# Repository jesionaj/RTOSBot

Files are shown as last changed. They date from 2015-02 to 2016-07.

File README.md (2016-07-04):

# RTOSBot
A small robot that uses my [HobbyOS](https://github.com/jesionaj/HobbyOS/) code. A video describing this project can be found [here](https://www.youtube.com/watch?v=qPOtINk6i20).

Robot

Parallax's Board of Education shield is the base of the robot, which includes the frame, motors, and encoders. For the brains, I laid out my own PCB with a PIC32MX250F128B chip, which you can find in the hardware folder.

PCB

The robot is driven using Wiimote Nunchuck. While it drives, the LCD on top displays encoder data and joystick position, which is also written to an SD card. After the driving is finished, that data can be copied off of the SD card (see below). An included Python script reads this data and reconstructs the robot's path using dead reckoning.

### Build Instructions
1. Run `git clone https://github.com/jesionaj/HobbyOS.git` in the RTOSBot folder.  
2. Open the RTOSBot project in MPLAB and hit build. That's it!

### Dead Reckoning  
The dead reckoning script requires Python 2.7, pygame 1.9.2, and numpy. Data is recorded on the SD card starting at address 0x400.  
1. Open the `python` folder and copy the data off the robot's SD card using (for OSX at least): `sudo dd bs=512 skip=2 if=/dev/rdisk# of=sdcard_data count=20`, where # is the SD card's disk number. Sample data is provided.  
2. Run `python InterpretFile.py sdcard_data`  
3. Before removing the SD card, run `sudo dd bs=512 seek=2 if=/dev/zero of=/dev/rdisk# count=20` to wipe out the old run.

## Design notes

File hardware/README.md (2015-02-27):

Included here are the Eagle project files for the PCB, as well as the gerber output.

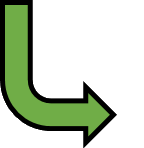
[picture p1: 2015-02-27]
python/img/orig/BackwardRight.png

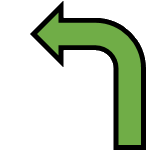
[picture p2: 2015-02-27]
python/img/orig/ForwardLeft.png

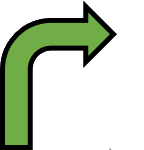
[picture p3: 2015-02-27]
python/img/orig/ForwardRight.png

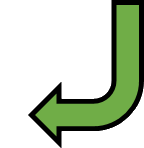
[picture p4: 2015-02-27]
python/img/orig/BackwardLeft.png

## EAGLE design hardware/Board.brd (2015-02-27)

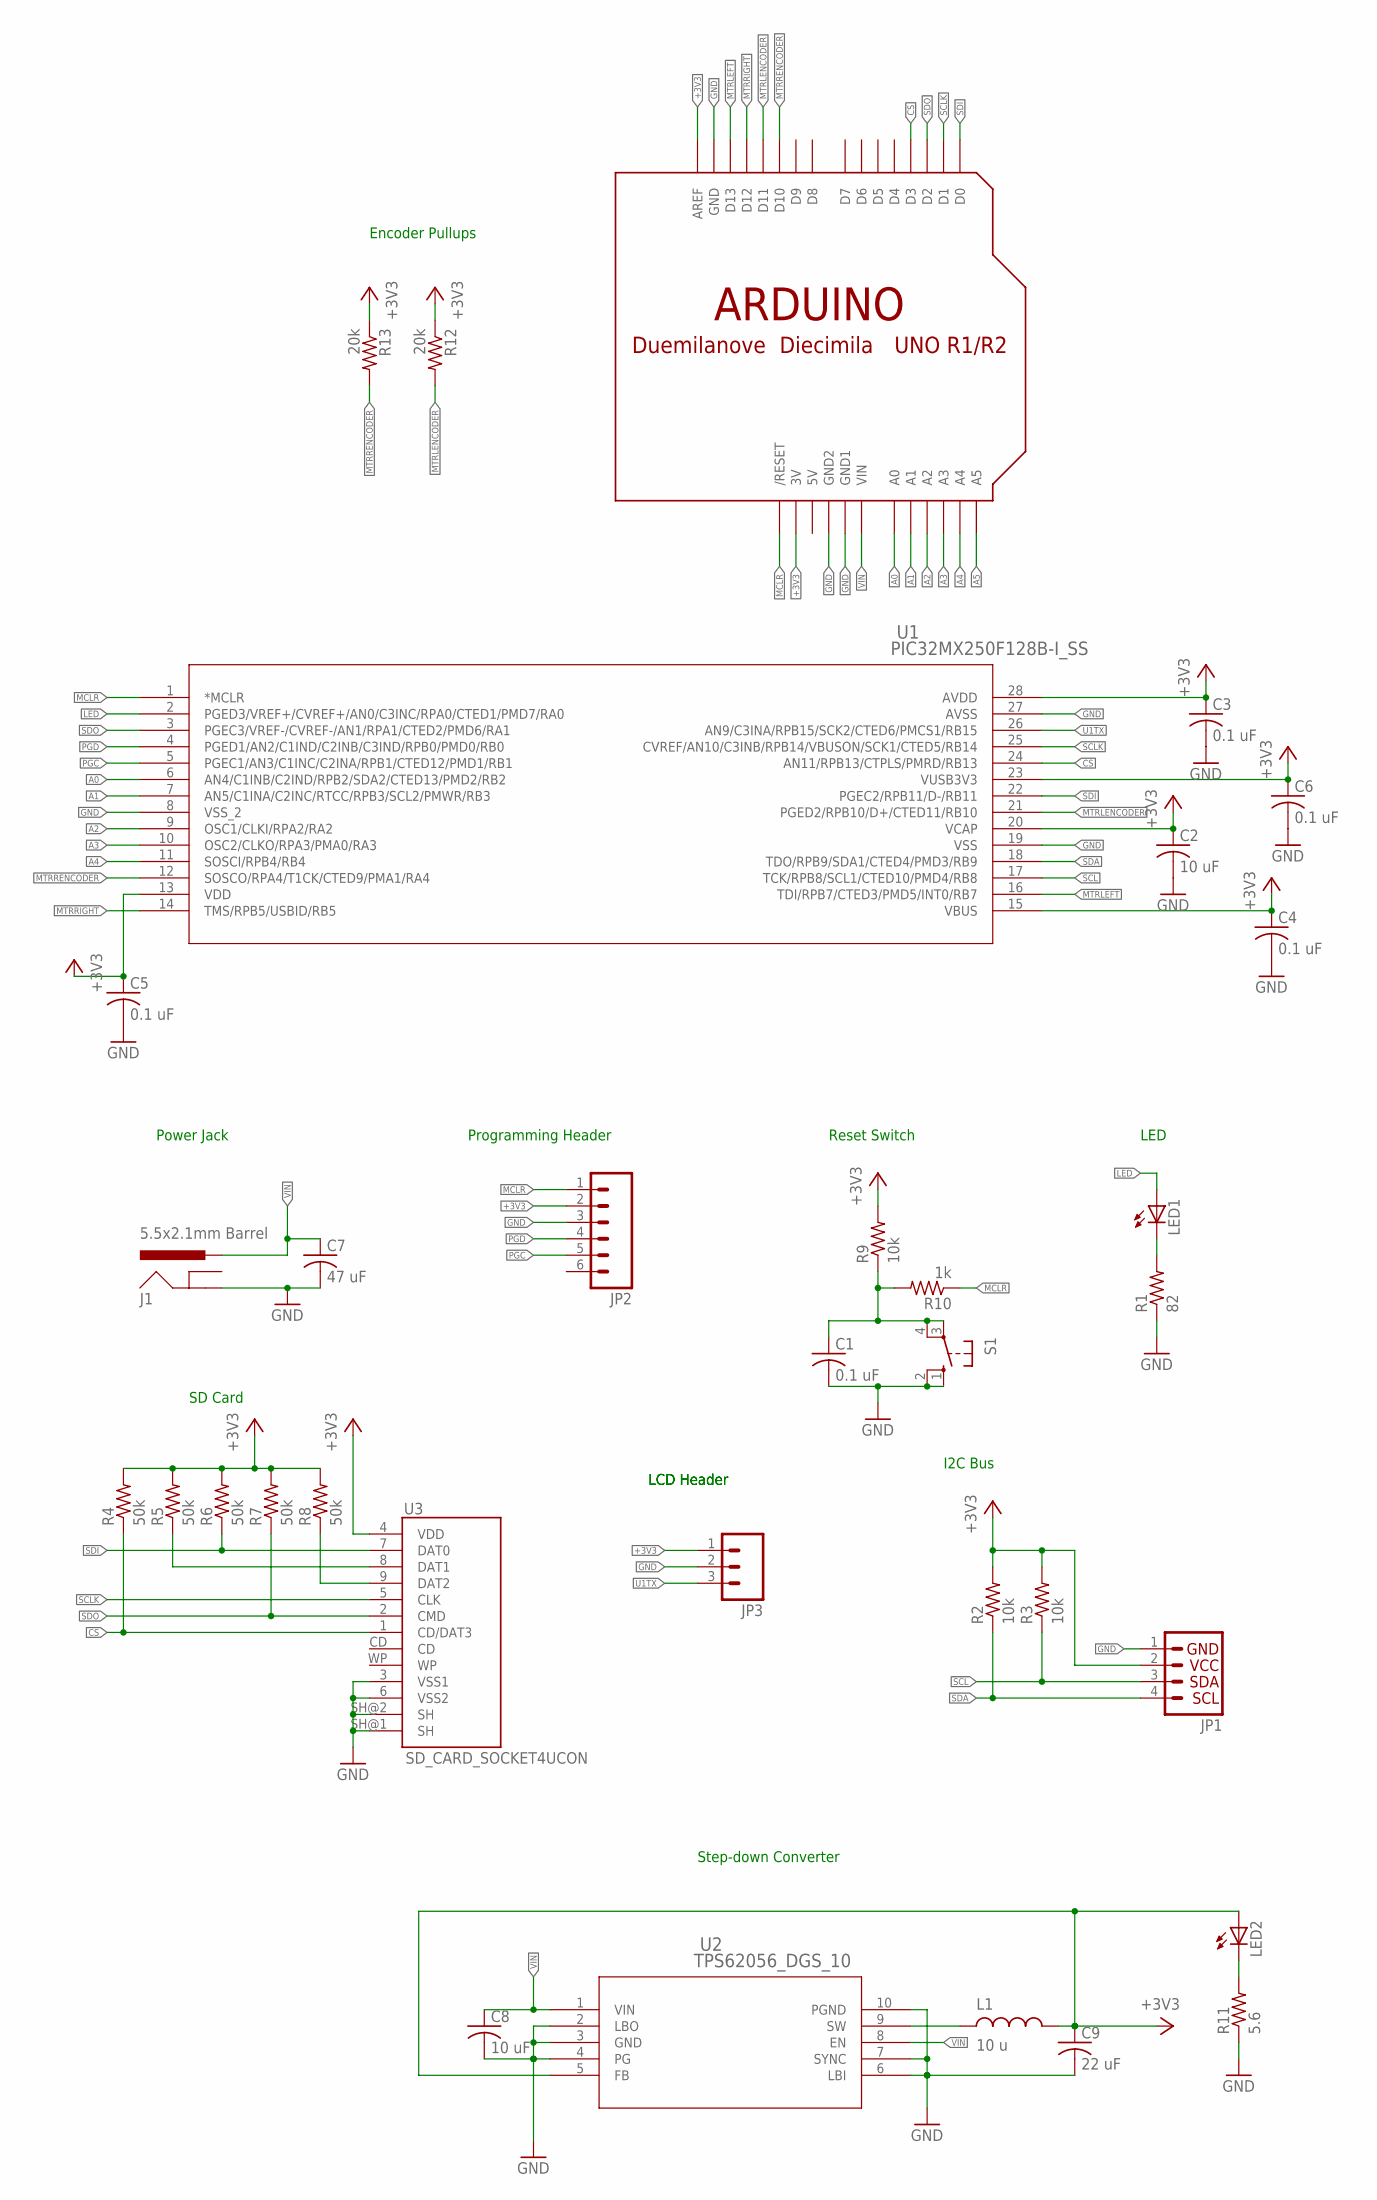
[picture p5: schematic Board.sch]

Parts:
C1, C3, C4, C5, C6: 0.1 uF; C0805
C2, C8: 10 uF; C0805
C7: 47 uF; C0805
C9: 22 uF; C0805
J1: 5.5x2.1mm Barrel; POWER_JACK_SMD
JP1: I2C_STANDARD; 1X04
JP2: M06SILK_FEMALE_PTH; 1X06
JP3: M03PTH; 1X03
L1: 10 u; SLF7032T-100M1R4-2PF
LED1, LED2: LEDCHIPLED_1206; CHIPLED_1206
R1: 82; R1210W
R2, R3, R9: 10k; R0805W
R4, R5, R6, R7, R8: 50k; R0805W
R10: 1k; R0805W
R11: 5.6; R1210W
R12, R13: 20k; R0805W
S1: 10-XX; B3F-10XX
U1: PIC32MX250F128B-I_SS; SSOP28_MC
U2: TPS62056_DGS_10; DGS10
U3: SD_CARD_SOCKET4UCON; SDCARD_4UCONN
U$1: ARDUINO-NOHOLE

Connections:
5V: U$1.5V
+3V3: C2.1, C3.1, C4.1, C5.1, C6.1, C9.1, JP1.2, JP2.2, JP3.1, L1.P$2, LED2.A, R2.2, R3.2, R4.2, R5.2, R6.2, R7.2, R8.2, R9.2, R12.1, R13.1, U1.13 (VDD), U1.15 (VBUS), U1.20 (VCAP), U1.23 (VUSB3V3), U1.28 (AVDD), U2.5 (FB), U3.4 (VDD), U$1.3V, U$1.AREF
A0: U1.6 (AN4/C1INB/C2IND/RPB2/SDA2/CTED13/PMD2/R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), U$1.A0
A1: U1.7 (AN5/C1INA/C2INC/RTCC/RPB3/SCL2/PMWR/RB3), U$1.A1
A2: U1.9 (OSC1/CLKI/RPA2/RA2), U$1.A2
A3: U1.10 (OSC2/CLKO/RPA3/PMA0/RA3), U$1.A3
A4: U1.11 (SOSCI/RPB4/RB4), U$1.A4
A5: U$1.A5
CS: R4.1, U1.24 (AN11/RPB13/CTPLS/PMRD/RB13), U3.1 (CD/DAT3), U$1.D3
GND: C1.2, C2.2, C3.2, C4.2, C5.2, C6.2, C7.2, C8.2, C9.2, J1.P$4 (GND), JP1.1, JP2.3, JP3.2, R1.1, R11.1, S1.1 (S), S1.2 (S1), U1.8 (VSS_2), U1.19 (VSS), U1.27 (AVSS), U2.2 (LBO), U2.3 (GND), U2.4 (PG), U2.6 (LBI), U2.7 (SYNC), U2.10 (PGND), U3.3 (VSS1), U3.6 (VSS2), U3.SH@1 (SH), U3.SH@2 (SH), U$1.GND, U$1.GND1, U$1.GND2
LED: LED1.A, U1.2 (PGED3/VREF+/CVREF+/AN0/C3INC/RPA0/CTED1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)
MCLR: JP2.1, R10.1, U1.1 (*MCLR), U$1.RESET (/RESET)
MTRLEFT: U1.16 (TDI/RPB7/CTED3/PMD5/INT0/RB7), U$1.D13
MTRLENCODER: R12.2, U1.21 (PGED2/RPB10/D+/CTED11/RB10), U$1.D11
MTRRENCODER: R13.2, U1.12 (SOSCO/RPA4/T1CK/CTED9/PMA1/RA4), U$1.D10
MTRRIGHT: U1.14 (TMS/RPB5/USBID/RB5), U$1.D12
unnamed: LED1.C, R1.2
unnamed: R8.1, U3.9 (DAT2)
unnamed: R5.1, U3.8 (DAT1)
unnamed: C1.1, R9.1, R10.2, S1.3, S1.4 (P1)
unnamed: LED2.C, R11.2
unnamed: L1.P$1, U2.9 (SW)
PGC: JP2.5, U1.5 (PGEC1/AN3/C1INC/C2INA/RPB1/CTED12/PMD1/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)
PGD: JP2.4, U1.4 (PGED1/AN2/C1IND/C2INB/C3IND/RPB0/PMD0/R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)
SCL: JP1.3, R3.1, U1.17 (TCK/RPB8/SCL1/CTED10/PMD4/RB8)
SCLK: U1.25 (CVREF/AN10/C3INB/RPB14/VBUSON/SCK1/CTED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), U3.5 (CLK), U$1.D1
SDA: JP1.4, R2.1, U1.18 (TDO/RPB9/SDA1/CTED4/PMD3/RB9)
SDI: R6.1, U1.22 (PGEC2/RPB11/D-/RB11), U3.7 (DAT0), U$1.D0
SDO: R7.1, U1.3 (PGEC3/VREF-/CVREF-/AN1/RPA1/CTED2/PMD6/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), U3.2 (CMD), U$1.D2
U1TX: JP3.3, U1.26 (AN9/C3INA/RPB15/SCK2/CTED6/PMCS1/RB15)
VIN: C7.1, C8.1, J1.VIN0 (PWR), U2.1 (VIN), U2.8 (EN), U$1.VIN

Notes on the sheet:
Reset Switch
SD Card
Programming Header
Power Jack
LCD Header
LED
I2C Bus
Step-down Converter
Encoder Pullups

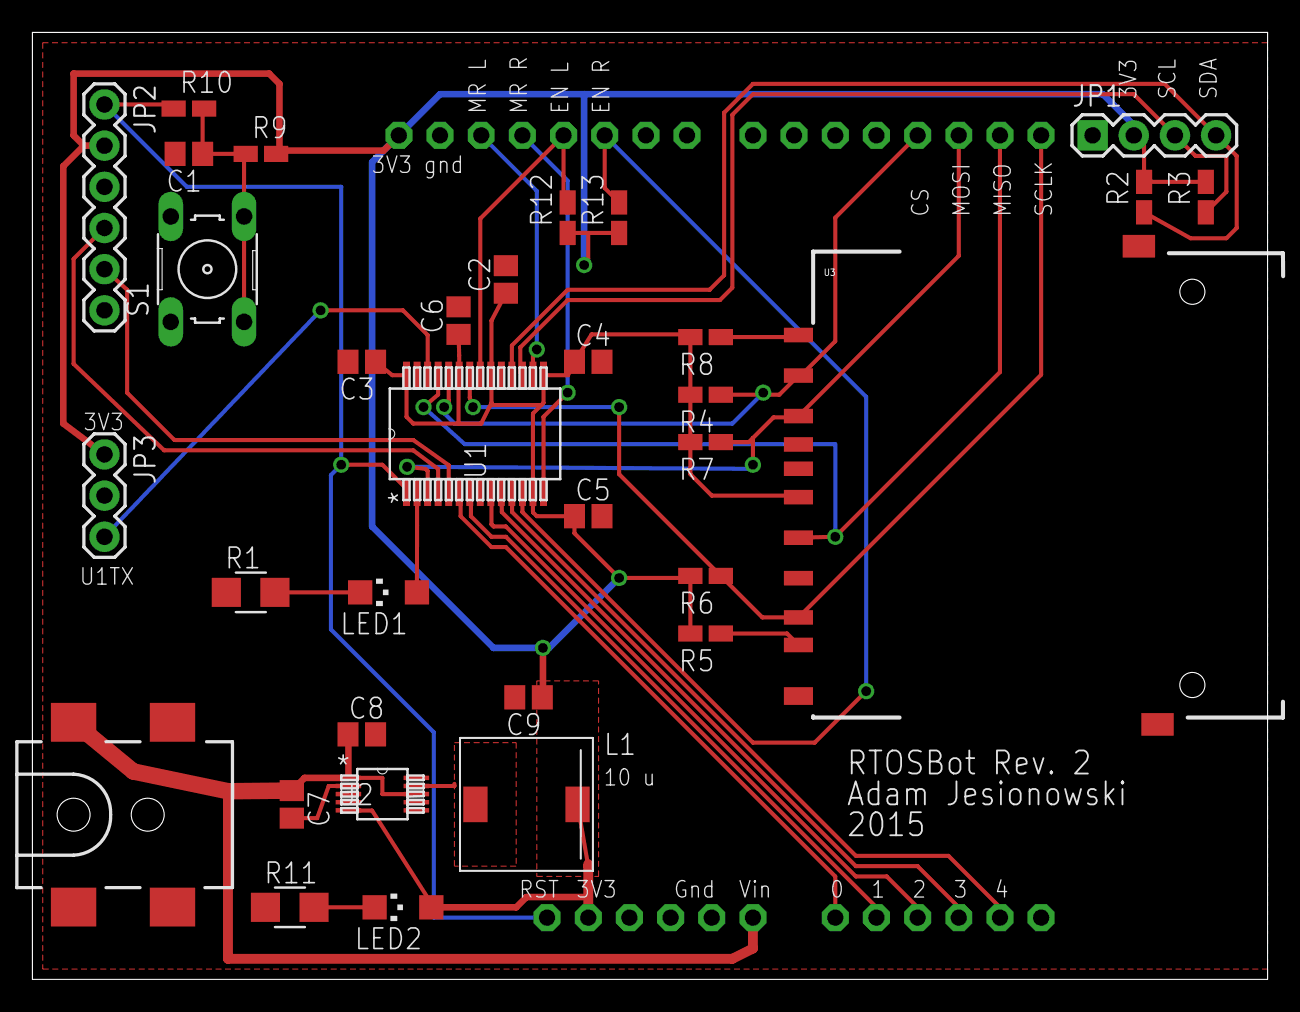
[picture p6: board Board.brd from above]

Board: 2 copper layers, 76.2 x 58.4 mm, 34 parts (0 on the bottom side), 29 nets.

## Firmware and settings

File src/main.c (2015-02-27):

// 2015 Adam Jesionowski

// Micro pinout:
// MCLR  1 --|         |-- 28 AVdd
// RA0   2 --|         |-- 27 GND
// RA1   3 --|         |-- 26 RB15
// Prgm  4 --|         |-- 25 RB14
// Prgm  5 --|         |-- 24 RB13
// RB2   6 --|         |-- 23 Vusb
// RB3   7 --|         |-- 22 RB11
// GND   8 --|         |-- 21 RB10
// RA2   9 --|         |-- 20 Vcap
// RA3  10 --|         |-- 19 GND
// RB4  11 --|         |-- 18 RB9
// RA4  12 --|         |-- 17 RB8
// Vdd  13 --|         |-- 16 RB7
// RB5  14 --|         |-- 15 VBus

// Connections:
// MCLR  1 --|         |-- 28 AVdd
// LED   2 --|         |-- 27 GND
// SDO   3 --|         |-- 26 U1TX
// Prgm  4 --|         |-- 25 SCLK
// Prgm  5 --|         |-- 24 CS
// Pin0  6 --|         |-- 23 Vusb
// Pin1  7 --|         |-- 22 SDI
// GND   8 --|         |-- 21 EncL
// Pin2  9 --|         |-- 20 Vcap
// Pin3 10 --|         |-- 19 GND
// Pin4 11 --|         |-- 18 SCA
// EncR 12 --|         |-- 17 SCL
// Vdd  13 --|         |-- 16 MtrL
// MtrR 14 --|         |-- 15 VBus

#include <xc.h>
#include <plib.h>

#include "rtos.h"
#include "port.h"
#include "blinkLED.h"
#include "serialLCD.h"
#include "motorTask.h"
#include "sdcard.h"
#include "wiimoteTask.h"
#include "encoder.h"

// Configuration Bits
#pragma config FNOSC = FRCPLL       // Internal Fast RC oscillator (8 MHz) w/ PLL
#pragma config FPLLIDIV = DIV_2     // Divide FRC before PLL (now 4 MHz)
#pragma config FPLLMUL = MUL_20     // PLL Multiply (now 80 MHz)
#pragma config FPLLODIV = DIV_2     // Divide After PLL (now 40 MHz)
                                    // see figure 8.1 in datasheet for more info
#pragma config FWDTEN = OFF         // Watchdog Timer Disabled
#pragma config ICESEL = ICS_PGx1    // ICE/ICD Comm Channel Select
#pragma config JTAGEN = OFF         // Disable JTAG
#pragma config FSOSCEN = OFF        // Disable Secondary Oscillator
#pragma config FPBDIV = DIV_2

void main(void)
{
    // Turn off JTAG
    DDPCONbits.JTAGEN = 0;

    SYSTEMConfig(SYS_FREQ, SYS_CFG_WAIT_STATES);

    // Initalize hardware and interrupts
    InitTickTimer();
    InitSoftwareInterrupt();
    InitHardwareTimer();
    InitI2C();
    InitEncoder();

    RTOS_Initialize();

    // Initialize tasks
    blinkLED_init();
    wiimoteTask_init();
    serialLCD_init();
    motorTask_init();
    sdCard_init();

    // Start tasks
    StartTask(&blinkLED_task);
    StartTask(&wiimoteTask_task);
    StartTask(&serialLCD_task);
    StartTask(&motorTask_task);
    StartTask(&sdCard_task);

    // Enable interrupts
    INTEnableSystemMultiVectoredInt();

    // Kick RTOS off
    StartFirstTask();

    // We should never get here.
    while(1);
}

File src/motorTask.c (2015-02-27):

// 2015 Adam Jesionowski

#include <xc.h>
#include <plib.h>
#include "motorTask.h"
#include "config.h"
#include "rtos.h"
#include "wiimoteTask.h"

/*
 * Servo datasheet:
 * http://www.parallax.com/sites/default/files/downloads/900-00008-Continuous-Rotation-Servo-Documentation-v2.2.pdf
 *
 * These servos work by sending a 1.3 to 1.7 millisecond pulse. 1.3 is full cw, 1.7 is ccw, 1.5 is stopped.
 * It also requires a 20 ms wait time between pulses, regardless of pulse size.
 */

static uintd_t motorTask_stack[DFLT_STACK_SIZE] = {0};
Task_t motorTask_task =
{
    PRIORITY_3,
    {NULL, NULL, &motorTask_task},
    0,
    motorTask_stack
};

// Speed is the max speed the servos can go, which is +/- 200 ms. Converted to timer counts:
// 200 ms = x/40 MHz/(8*2) (8 prescalar on pb clock, which is 40 MHz/2), means x = 500
#define SPEED 500

// TODO: We do want a queue size of 1, but we want the newest data to take effect rather than
// dropping off. Not an issue for the way our code is set up (the intervals are slow enough
// that we won't run into issues with overflow), but could be useful in the future.
#define QUEUE_SIZE 1
static JoystickInput_t motorInputQueueStorage[QUEUE_SIZE];
Queue_t motorInputQueue;

// Direction each motor is heading
static volatile int8_t leftDirection;
static volatile int8_t rightDirection;

static bool InRange(uint8_t xIn, uint8_t yIn, uint8_t x, uint8_t y);
static void SetLeftPWM(uint16_t speed);
static void SetRightPWM(uint16_t speed);

/*
 * This gives the encoders a way of knowing where the motors are going
 */
void __inline GetMotorDirection(int8_t* leftDir, int8_t* rightDir)
{
    *leftDir  = leftDirection;
    *rightDir = rightDirection;
}

void motorTask_init()
{
    motorTask_task.stackPtr = &motorTask_stack[DFLT_STACK_SIZE-1];
    motorTask_task.stackPtr = (uintd_t*)InitStack(motorTask_task.stackPtr, motorTask_main);

    InitQueue(&motorInputQueue, (uint8_t*)motorInputQueueStorage, sizeof(JoystickInput_t), QUEUE_SIZE);

    mPORTBSetPinsDigitalOut(BIT_5 | BIT_7);
    PPSOutput(1,RPB7,OC1); // Set RPB7 pin as output for output compare module -- Left
    PPSOutput(2,RPB5,OC2); // Set RPB5 pin as output for output compare module -- Right

    // Default periods is 53750, where 50,000 = 20 ms off time, 3750 = 1.5 ms pulse time
    OpenTimer2(T2_ON | T2_PS_1_8, 53750);
    OpenTimer3(T3_ON | T3_PS_1_8, 53750);

    OpenOC1( OC_ON  | OC_TIMER2_SRC | OC_PWM_FAULT_PIN_DISABLE | OC_LOW_HIGH , 0, 0 );
    OpenOC2( OC_ON  | OC_TIMER3_SRC | OC_PWM_FAULT_PIN_DISABLE | OC_LOW_HIGH , 0, 0 );

    SetDCOC1PWM(3750);
    SetDCOC2PWM(3750);

    leftDirection  = 1;
    rightDirection = 1;
}

// Defines the range of values for which the joystick can fall into
#define RANGE 15

/*
 * Returns true if xIn and yIn are in range of the x and y
 */
static bool InRange(uint8_t xIn, uint8_t yIn, uint8_t x, uint8_t y)
{
    bool result = false;

    if(xIn > (x - RANGE) && xIn < (x + RANGE))
    {
        if(yIn > (y - RANGE) && yIn < (y + RANGE))
        {
            result = true;
        }
    }

    return result;
}

/*
 * Set the PWM registers.
 * These functions take a speed value from -500 to 500, and set the period and PWM registers accordingly.
 * The period needs to be changed as the servos required 20 ms of time inbetween the pulse times.
 */
static void SetLeftPWM(uint16_t speed)
{
    uint16_t adjustedSpeed = speed + 3750;
    uint16_t timerValue = 50000 + adjustedSpeed;
    SetDCOC1PWM(adjustedSpeed);

    T2CON = T2_PS_1_8;
    if(TMR2 > timerValue)
    {
        TMR2 = 0;
    }

    PR2 = timerValue;
    T2CONSET = T2_PS_1_8 | T2_ON;
}

static void SetRightPWM(uint16_t speed)
{
    uint16_t adjustedSpeed = speed + 3750;
    uint16_t timerValue = 50000 + adjustedSpeed;
    SetDCOC2PWM(adjustedSpeed);

    T3CON = T3_PS_1_8;
    if(TMR3 > timerValue)
    {
        TMR3 = 0;
    }
    
    PR3 = timerValue;
    T3CONSET = T3_PS_1_8 | T3_ON;
}

void motorTask_main()
{
    JoystickInput_t input;
    int16_t oldR = 0;
    int16_t oldL = 0;

    while(1)
    {
        DequeueBlocking(&motorInputQueue, (uint8_t*)&input);

        int16_t l = 0;
        int16_t r = 0;

        // The x and y values were found by recording the values for pushing the joystick
        // all the way in that direction. If it fits into none, just keep the default 0/0 central value
        if(InRange(input.x, input.y, 113, 217))
        {
            // Forward
            l = SPEED;
            r = -SPEED;
        }
        else if(InRange(input.x, input.y, 128, 18))
        {
            // Backward
            l = -SPEED;
            r = SPEED;
        }
        else if(InRange(input.x, input.y, 222, 115))
        {
            // Right
            l = SPEED;
            r = SPEED;
        }
        else if(InRange(input.x, input.y, 19, 128))
        {
            // Left
            l = -SPEED;
            r = -SPEED;
        }
        else if(InRange(input.x, input.y, 54, 164) || InRange(input.x, input.y, 15, 164))
        {
            // Forward Left
            // This one is a little weird, as it's either 54/164 or 8/164
            l = SPEED/8;
            r = -SPEED;
        }
        else if(InRange(input.x, input.y, 176, 153))
        {
            // Forward Right
            l = SPEED;
            r = -SPEED/8;
        }
        else if(InRange(input.x, input.y, 54, 52))
        {
            // Backward Left
            l = -SPEED/8;
            r = SPEED;
        }
        else if(InRange(input.x, input.y, 176, 54))
        {
            // Backward Right
            l = -SPEED;
            r = SPEED/8;
        }

        // Account for the way left and right motors are flipped
        if(l >= 0)
        {
            leftDirection = 1;
        }
        else
        {
            leftDirection = -1;
        }

        if(r < 0)
        {
            rightDirection = 1;
        }
        else
        {
            rightDirection = -1;
        }

        // Set PWM if the speeds for each motor has changed
        if(oldL != l)
        {
            SetLeftPWM(l);
            oldL = l;
        }

        if(oldR != r)
        {
            SetRightPWM(r);
            oldR = r;
        }
    }
}

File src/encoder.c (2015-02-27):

// 2015 Adam Jesionowski

#include <xc.h>
#include <plib.h>
#include "config.h"
#include "motorTask.h"
#include "port.h"

static volatile bool lastRight;
static volatile bool lastLeft;

static volatile int8_t lCount;
static volatile int8_t rCount;

/*
 * Initialize change notification interrupt
 */
void InitEncoder()
{
    mPORTASetPinsDigitalIn(BIT_4);
    mPORTBSetPinsDigitalIn(BIT_10);

    lastRight = mPORTAReadBits(BIT_4);
    lastLeft  = mPORTBReadBits(BIT_10);

    mCNAOpen(CNA_ON, CNA4_ENABLE,  CNA_PULLUP_DISABLE_ALL);
    mCNBOpen(CNB_ON, CNB10_ENABLE, CNB_PULLUP_DISABLE_ALL);

    // Read corresponding registers to clear mismatch condition on CN input pins
    mPORTARead();
    mPORTBRead();

    // Set up the interrupt
    ConfigIntCNA(CHANGE_INT_ON | CHANGE_INT_PRI_2);
    ConfigIntCNB(CHANGE_INT_ON | CHANGE_INT_PRI_2);

    INTSetVectorPriority(INT_CHANGE_NOTICE_VECTOR, INT_PRIORITY_LEVEL_2);
    INTSetVectorSubPriority(INT_CHANGE_NOTICE_VECTOR, INT_SUB_PRIORITY_LEVEL_0);

    // Clear CN interrupt flag
    INTClearFlag(INT_CNA);
    INTClearFlag(INT_CNB);
}

/*
 * ISR for Change Notification
 */
void __ISR(_CHANGE_NOTICE_VECTOR, ipl2) EncoderIntWrapper(void);
void EncoderInt(void)
{
    // Read corresponding registers to clear mismatch condition on CN input pins
    uint16_t portA = mPORTARead();
    uint16_t portB = mPORTBRead();

    // Clear the interrupt flags
    // If one of these interrupts kicked things off but the other became true in the intervening period,
    // it's still okay to clear it here, as the change will be processed below
    INTClearFlag(INT_CNA);
    INTClearFlag(INT_CNB);

    // If right is different than from the last interrupt:
    if(lastRight != (bool)(portA & BIT_4))
    {
        lastRight = (bool)(portA & BIT_4);
        rCount++;
    }

    // If left is differrent than from the last interrupt:
    if(lastLeft != (bool)(portB & BIT_10))
    {
        lastLeft = (bool)(portB & BIT_10);
        lCount++;
    }
}

/*
 * Return and reset current encoder counts
 */
void __inline GetAndResetCounts(int8_t* left, int8_t* right)
{
    ENTER_CRITICAL_SECTION;
    *left  = lCount;
    *right = rCount;
    lCount = 0;
    rCount = 0;
    EXIT_CRITICAL_SECTION;
}

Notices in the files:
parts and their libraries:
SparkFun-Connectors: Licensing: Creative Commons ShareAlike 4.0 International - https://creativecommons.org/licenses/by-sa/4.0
